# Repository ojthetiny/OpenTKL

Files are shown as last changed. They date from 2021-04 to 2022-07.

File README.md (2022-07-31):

# OpenTKL

Fully open souce TKL keyboard project


Use as a base for your own designs, renders or order as is (read important info at the bottom).

Details:
 - F13 TKL layout supporting ANSI, ISO, stepped and normal CAPS, Split right shift, and split backspace.
 - Jane V2 CE plate.
 - 3 optional internal weight pieces can be filled with foam for dampening or metal for more heft.
 - 7 degree typing angle.
 - Hiney h88c support.
 - Flush USB-C connector built into the PCB, no need for a daughterboard (though the PCB supports it).
 - Skuf feet.
 - Countersunk m3 screws for everything except the plate which uses normal button head m3 screws.

Important Info (READ BEFORE ORDERING):
 - I do not offer any sort of warranty for this, nor can I be held liable if something goes wrong.
 - Renders are not fully representative of the final product.
 - Please, PLEASE look over the design before you do anything with it, it's possible and very likely that there are some errors, I'm just a human.

If you use this as a template for your own design, please give credit(same goes for renders).

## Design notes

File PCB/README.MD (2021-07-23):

# PCB

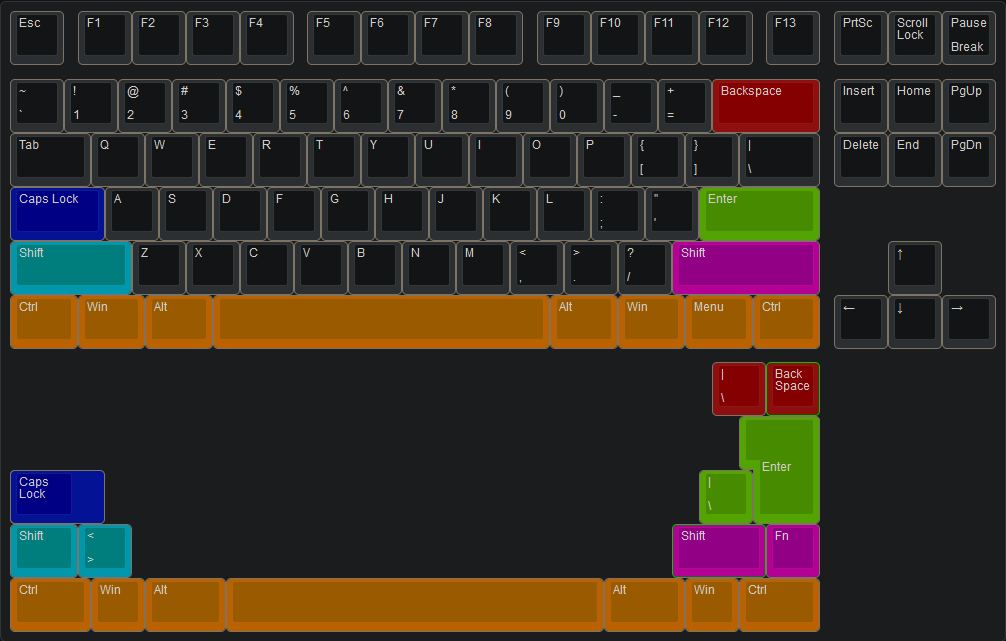
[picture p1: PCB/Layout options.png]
Layout Options


Features:
 - Top Mount USB-C or Unified Daughterboard.
 - In switch indicator lights for Caps Lock, Scroll Lock, and Layer on Esc.
 - Atmega 32u4-mu MCU
 - Support for both MX and Alps switches
 - Support for gummy worm mount boards, tabs in the same spaces as Hineys h88 pcb
 - RGB breakout between the nav and arrow clusters for 1.2og like designs
 - ISP breakout for if you know what you're doing ;)

IMPORTANT:
 - This PCB is untested for now, there may be errors in the design, no warranty offered yada yada
 - Footprint identical to h88c

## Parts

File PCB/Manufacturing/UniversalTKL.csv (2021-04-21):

Comment | Designator | Footprint | LCSC
.1u | C_DECOUP1,C_DECOUP2,C_DECOUP3 | Capacitor_SMD:C_0402_1005Metric | C1525
10u | C_DECOUP4 | Capacitor_SMD:C_0402_1005Metric | C15525
1u | C_UCAP1 | Capacitor_SMD:C_0402_1005Metric | C52923
BAV70_Small | D1,D2,D3,D4,D5,D6,D7,D8,D9,D10,D11,D12,D13,D14,D15,D16,D17,D19,D20,D21,D22,D23,D24,D25,D26,D27,D28,D29,D30,D31,D32,D33,D34,D35,D36,D37,D38,D39,D40,D41,D42,D43,D44,D45 | Package_TO_SOT_SMD:SOT-23 | C68978
PRTR5V0U2X | D18 | Package_TO_SOT_SMD:SOT-143 | C558444
D_Small | D46,D47,D48 | Diode_SMD:D_SOD-123 | C64898
SK6812MINI | D49,D50,D51,D52,D53,D54,D55,D56,D57,D58,D59,D60,D61,D62,D63,D64,D65,D66,D67,D68,D69,D70,D71,D72,D73,D74,D75,D76,D77,D78 | LED_SMD:LED_SK6812MINI_PLCC4_3.5x3.5mm_P1.75mm
Polyfuse_Small | F1 | Fuse:Fuse_0805_2012Metric | C151162
Reset Jumper | J1 | Button_Switch_SMD:SW_SPST_TL3342
CONN_RGB | J2 | Connector_PinHeader_2.54mm:PinHeader_1x03_P2.54mm_Vertical
CONN_DB | J3 | Connector_JST:JST_SH_SM04B-SRSS-TB_1x04-1MP_P1.00mm_Horizontal | C160404
MX-LED | MX1 | MX_Alps_Hybrid:MX-1.25U
MX-NoLED | MX2,MX3,MX10,MX17,MX60,MX61,MX73,MX81 | MX_Alps_Hybrid:MX-1.25U-NoLED
MX-NoLED | MX39 | MX_Alps_Hybrid:MX-6.25U-ReversedStabilizers-NoLED
MX-LED | MX4,MX95 | MX_Alps_Hybrid:MX-1U
MX-NoLED | MX45 | MX_Alps_Hybrid:MX-7U-ReversedStabilizers-NoLED
MX-NoLED | MX5,MX11,MX12,MX13,MX14,MX15,MX16,MX18,MX19,MX20,MX21,MX22,MX24,MX25,MX26,MX27,MX28,MX29,MX30,MX31,MX32,MX33,MX34,MX35,MX36,MX37,MX38,MX40,MX41,MX42,MX43,MX44,MX46,MX47,MX48,MX49,MX50,MX51,MX52,MX53,MX54,MX55,MX56,MX57,MX58,MX59,MX62,MX63,MX64,MX65,MX66,MX68,MX69,MX70,MX71,MX74,MX75,MX76,MX77,MX79,MX82,MX83,MX85,MX87,MX88,MX91,MX92,MX93,MX94,MX96,MX97,MX98,MX99,MX100,MX101,MX102,MX103 | MX_Alps_Hybrid:MX-1U-NoLED
MX-NoLED | MX6,MX9,MX23,MX67,MX86,MX90 | MX_Alps_Hybrid:MX-1.5U-NoLED
MX-LED | MX7 | MX_Alps_Hybrid:MX-1.75U
MX-NoLED | MX72 | MX_Alps_Hybrid:MX-2.75U-NoLED
MX-NoLED | MX78 | MX_Alps_Hybrid:MX-1.75U-NoLED
MX-NoLED | MX8 | MX_Alps_Hybrid:MX-2.25U-NoLED
MX-NoLED | MX80 | MX_Alps_Hybrid:MX-ISO-ReversedStabilizers
MX-NoLED | MX84 | MX_Alps_Hybrid:MX-2.25U-ReversedStabilizers-NoLED
MX-NoLED | MX89 | MX_Alps_Hybrid:MX-2U-NoLED
22 | R_DATA1,R_DATA2 | Resistor_SMD:R_0402_1005Metric | C25092
10k | R_HWB1,R_RST1 | Resistor_SMD:R_0402_1005Metric | C25744
220 | R_INDICATOR1,R_INDICATOR2,R_INDICATOR3 | Resistor_SMD:R_0402_1005Metric | C25091
5k1 | R_USB1,R_USB2 | Resistor_SMD:R_0402_1005Metric | C25905
ATmega32U4-M | U1 | Package_DFN_QFN:QFN-44-1EP_7x7mm_P0.5mm_EP5.2x5.2mm | C45874
HRO-TYPE-C-31-M-12 | USB1 | Components:HRO-TYPE-C-31-M-12-Assembly | C165948
Resonator_Small | Y1 | Crystal:Resonator_SMD_Murata_CSTxExxV-3Pin_3.0x1.1mm | C32180

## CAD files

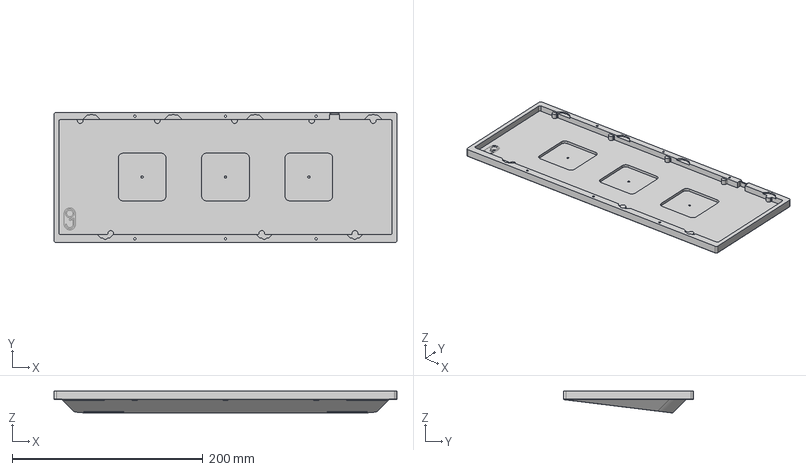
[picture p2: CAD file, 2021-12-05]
Case/Raw CAD/OpenTKL_Bottom.step
359.6 x 136.5 x 23.0 mm

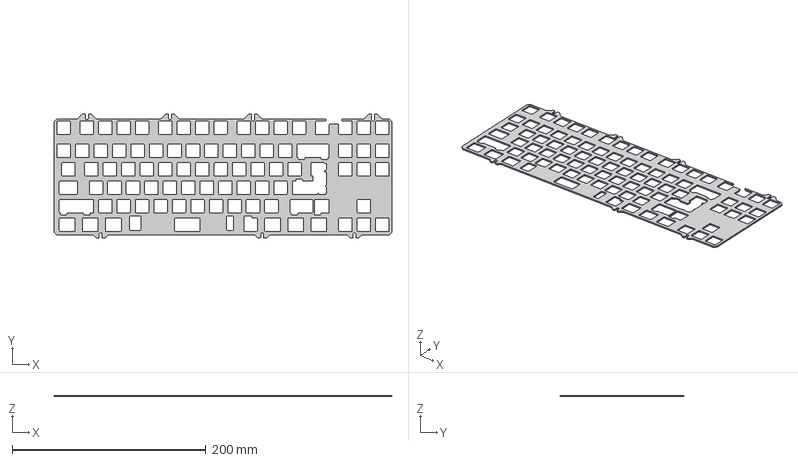
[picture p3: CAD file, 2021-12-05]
Case/Raw CAD/OpenTKL_Plate.step
348.7 x 128.0 x 1.50 mm

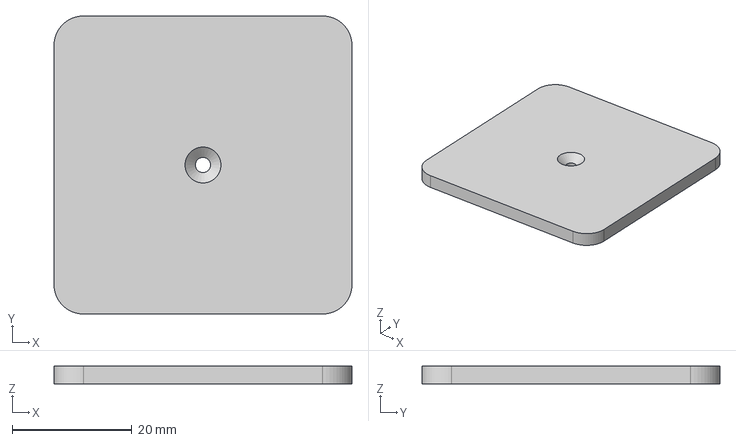
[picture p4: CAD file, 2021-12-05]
Case/Raw CAD/OpenTKL_Weight.step
49.8 x 49.8 x 3.00 mm

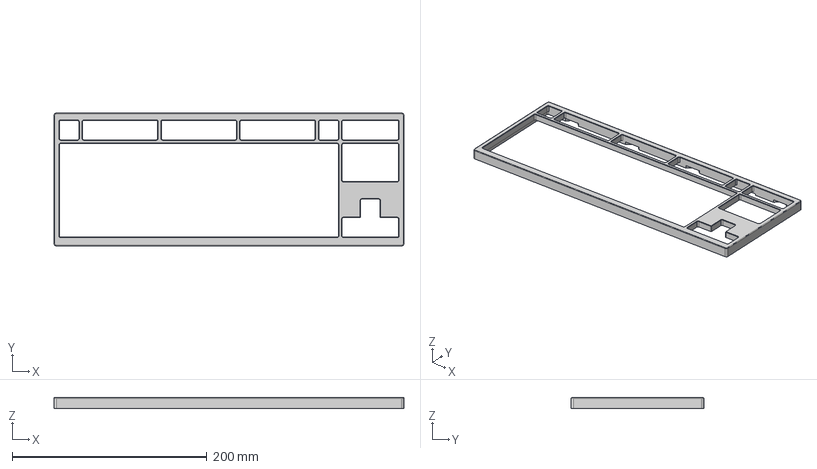
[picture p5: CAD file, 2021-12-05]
Case/Raw CAD/OpenTKL_Top.step
359.6 x 136.5 x 11.2 mm

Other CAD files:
Case/Raw CAD/OpenTKL_plate.dxf

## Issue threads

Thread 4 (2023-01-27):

PCB matrix design

Pyrykoi, 2023-01-27:
Based on what did you design the pcb matrix? It seems that every button is a double with a button next to it (e.g. there is two row0 col0). Does bav70 diode do something there? p.s. puhun myös suomea jos helpompi selittää.

-Pyry

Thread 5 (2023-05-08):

Can someone please make a f12 version of the top case?

cwelpawel, 2023-05-08:
I would really appreciate if someone changed the top part of the case to a different layout that doesn't have the f13 key. I would do that myself if i only knew how to do so, but i don't have the skills needed to modify the file to match my preferrence.

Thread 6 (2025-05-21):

Modified the 3d files to make a 3d printable version. (Also made a numpad)

cSmakerVT, 2025-05-21:
I really loved this project and it was perfect for me because I had an extra Freebird tkl pcb laying around. I made some modifications to the step file so the board can be printed on the average size 3d printer build plate. I also tweaked the mounting points a little so that the keyboard will come together nicely when printed.

I also made a numpad to go with it (trying to follow the design as best I could). The numpad may need some slight modifications, but I designed it to be hand wired but could convert it with a little work. I did not take the time to make a pcb for the numpad but shouldn't be too hard with the given Kicad files.

If anyone is interested I would be happy to share the files on a new branch. I am very grateful for this project being open sourced it saved me a lot of work and possibly prevented my extra pcb from being e-waste.

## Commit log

2021-04-21 added pic of layout options on PCB
2021-04-21 Created PCB readme
2021-04-21 Fixed some things in the case files
    designer forgot filets xD
    [Bottom Case.step, Top Case.step]
2021-07-17 Fixed PCB, Changed to Support Jane Plate
    [OpenTKL_Bottom.step, OpenTKL_Bottom.stl, OpenTKL_Plate.step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]
2021-07-17 removed unnecessary files
    [Bottom Case.step, Plate.dxf, Plate.step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]
2021-08-02 fixed openTKL pos and gerber files
    title
2021-12-05 de-scuffified the design
    [Bottom Case_OpenTKL.stl, OpenTKL_Bottom.step, OpenTKL_Bottom.stl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]
